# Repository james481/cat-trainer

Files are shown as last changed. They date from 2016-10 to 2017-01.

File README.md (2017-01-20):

# Cat Trainer

## Electronic Feline Warfare for Fun and Profit

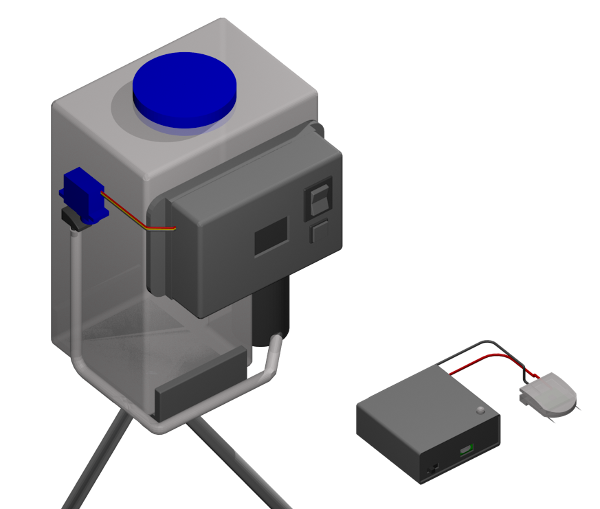
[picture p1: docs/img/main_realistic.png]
Cat Trainer


A microcontroller based system for training cats using accelerometer based sensors to detect clawing of carpet or furniture and automatically discouraging the behavior using sprayed water.

See more details about this project and how it was built [here](https://james481.github.io/cat-trainer/).

__This project has been featured on [Hackaday](http://hackaday.com/2017/01/20/sentry-robot-turns-bad-cat-to-good/). Welcome HaD readers and thanks for checking it out!__

* [Base Software](./base/teensy_base)
* [Base PCB - OSHPark](https://oshpark.com/shared_projects/nA5DhVjQ)
* [Base KiCad Schematic / PCB](./base/teensy_base_pcb)
* [Sensor Software](./sensor/arduino_mma8452)
* [Sensor PCB - OSHPark](https://oshpark.com/shared_projects/1HsJuNbs)
* [Sensor KiCad Schematic / PCB](./sensor/feather32u4_mma8452_pcb)

All code and other materials contained in this repository are copyright (c) 2016 - 2017 James Watts or their respective copyright holders as noted, and is provided under BSD license. For details see [LICENSE.txt](LICENSE.txt).

This device is patent pending. Please [contact me](http://www.jamescwatts.com) for licensing or more information.

[main]: ./docs/img/main_realistic.png

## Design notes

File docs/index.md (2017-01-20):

---
title: Electronic Feline Warfare for Fun and Profit
---

__This project has been featured on [Hackaday](http://www.hackaday.com). Welcome HaD readers and thanks for checking it out!__

## The Problem

My wife and I have a couple of cats in our home, and as any cat owners can tell you they pretty much spend their days either napping or causing problems. One particular problem our cats cause is tearing up the carpets and furniture in our home. This sight is familiar to many cat owners:

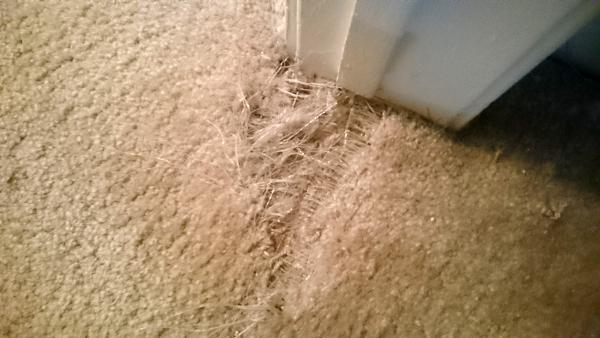
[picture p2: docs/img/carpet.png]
Torn Carpet


We stopped our cats from doing this while we were around by spraying them with a regular hand spray bottle full of water, but as evidenced by the bits of carpet laying everywhere, they still continued doing it when we weren't around to stop them.

---

## The Answer

Cat Trainer

Having recently become interested in programming microcontrollers, I decided to work on an automated solution to my problem. After tinkering with it for a while (close to a year off and on), I ended up building a system based on a central control and spray station gathering data from wireless sensor nodes attached to the carpet near the spots the cats tear up. When the cats pull on the carpet with their claws activating one of the sensors, the base station points a spray nozzle towards the activated sensor and activates a small pump, spraying the cat with water, thus enacting sweet, sweet revenge (and also training them to not scratch in that spot any more).

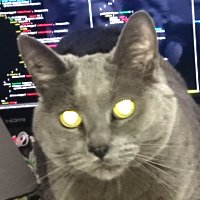
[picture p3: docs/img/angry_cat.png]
Angry Cat


---

## The Design

The first problem to solve was how to detect when my cat was tearing up the carpet with some sort of sensor. Along with detecting the scratching, I wanted the sensor to ignore the cats when they weren't tearing the carpet and just passing by, and also all the other exciting things that happen in the life of a carpet, like being walked on or vacuumed.

### The Sensor Unit

After some testing, I determined that I could detect the motion that the cats clawing causes in the carpet fairly reliably by using an accelerometer set to only report the motion of the carpet being pulled away from the floor underneath by the cat's claws. I ended up choosing the MMA8452Q integrated accelerometer from Freescale Semiconductors, handily available on a fairly inexpensive breakout board from [SparkFun](https://www.sparkfun.com/products/12756). This IC is something similar to what you might find in your cell phone to detect when you turn it on it's side, but reading through the (rather extensive) [data sheet](https://cdn.sparkfun.com/datasheets/Sensors/Accelerometers/MMA8452Q-rev8.1.pdf) yields all sorts of other interesting abilities.

Particular to my needs is the ability to configure the accelerometer IC to internally handle detection of motion events above certain thresholds and in certain axes (so called "transient motion detection"), and to fire interrupts by changing the voltage states of it's external pins when it detects these motion events. This allows the microcontroller to normally run in a very low power state and not constantly monitor the raw sensor data, increasing the sensor node battery life substantially. The sensor IC sitting on it's small breakout board fits snugly in a molded plastic clip designed for hanging papers on cubicle walls, which work perfectly for attaching the sensor temporarily to the carpet.

Accelerometer Sensor

After figuring out what sensor to use, I next needed a microcontroller that could run the sensor a report the data back to the base station using some wireless radio. I considered using an ESP8266 WiFi board, but quickly ran into problems with the power characteristics of that chip, in that it has a low power operating mode, but takes a couple of seconds to resume wireless operation after coming out of sleep, so wouldn't work well for this real time usage. I ended up prototyping the sensor using a basic Arduino Pro Mini / Atmel 328p using a [Nordic NRF24L01+](https://www.amazon.com/gp/product/B00NGCZC0M) 2.4GHz radio chipset for wireless packet communication, along with a RGB LED for status / battery level notification.

Sensor Prototype

The final implemented sensor nodes use a [Feather / Atmel 32u4 board](https://www.adafruit.com/products/2771) from Adafruit and the same Nordic radio chips along with a [1Ah Li-Ion battery](https://www.sparkfun.com/products/13813) for power. The Feather boards are nice because they have the power regulation and charging circuitry for the battery on-board, and also have a voltage divider at the battery input already connected to an analog pin, making monitoring the battery level in software very easy. Finally, they break out the enable pin of the voltage regulator, making adding an on / off switch easy as well. I built the first one by wiring everything together by hand with soldering and short lengths of wire.

Sensor Hand Built

I decided after building the first one that a [PCB](https://oshpark.com/shared_projects/1HsJuNbs) would be much easier than wiring everything by hand, and makes everything look a bit cleaner to boot (although this PCB design has a couple of minor fit issues I'd like to fix).

Sensor PCB

Either way, everything is put into a small [plastic enclosure](https://www.digikey.com/product-detail/en/bud-industries/HP-3650-B/377-1650-ND/2057365) with some silicone wires (JST-XH battery balance extensions) to connect the sensors. Having the sensor units pretty well squared away I moved on to the central control / spray unit, which ended up being somewhat more complex.

---

### The Base Unit

I wanted the base spray unit to handle several tasks:

* Securely contain water used for spraying in a bottle / reservoir
* Pump water through a spray nozzle to create the spray when a sensor is activated
* Allow connection of multiple sensors to cover a larger area
* Position the spray nozzle to point towards the sensor being activated
* Display the battery level and activation counts of the connected sensors
* Allow configuration of the direction for spray for each sensor

This is a lot to ask of one of the smaller Arduino / Atmel boards like the Pro Mini or Feather (although it's probably possible), so I chose a [Teensy 3.2](https://www.pjrc.com/store/teensy32.html) board to power the operation of the base station. This little fella sports a fairly impressive ARM Cortex M4 running at 72 MHz and plenty of flash / RAM / GPIO to play with. Like with the sensor the initial prototype was built on a bread board.

Base Unit Prototype

#### Water Bottle / Pump

The main component of the base station is the water storage and pump to drive the spray nozzle. Lots of different possibilities exist for making something from scratch (especially if a 3d printer is handy), but I decided to just get a pre-built automotive [windshield washer tank](https://www.amazon.com/gp/product/B00495UQT2). This holds much more water than I need, but having the pump built in makes it a convenient part to start with. The pump is designed to run on 12V (as you find in an automobile) but pushes plenty well when given 9V (pulling momentary loads of 1.6A or so). Bonus is that it came with tubing and some spray nozzles (as might be mounted on the hood of your car) and assorted hardware. I used one of the spray nozzles after plugging one side of it with epoxy to spray in a single direction, and some of the hardware to build the mount.

#### Control Spray Nozzle Direction

To position the spray nozzle in different directions to cover multiple sensors, I decided to keep things as simple as possible. I used a [small hobby RC type servo](https://www.amazon.com/gp/product/B0006O3WNW) that I positioned upside down on a simple wire mount epoxied on the side of the tank. This mount also has a horizontal bracket to hold the spray nozzle fitting (that came with the kit). A simple screw straight down through the servo horn into the plastic housing of the spray nozzle completes the connection and allows a fairly wide range (160 degrees or so) of direction adjustment. Modding the servo for continuous rotation or switching to a small stepper motor along with changing the mounting could increase the adjustment range, or for even more mobility the whole thing could be mounted on a mobile chassis.

Spray Nozzle

#### Display Status / Control Sensor Spray Direction

The connected sensor nodes are displayed as icons indicating their current battery level along with the configured direction for them and a count of how many sensor activations have been received on a "postage stamp" [OLED display](https://www.amazon.com/gp/product/B00O2KDQBE). A menu system allows configuration of the base station and connected sensor spray directions via a three position toggle switch and push button (up / down / enter). These are mounted on the outside of a [plastic case](https://www.digikey.com/product-detail/en/bud-industries/CU-18428-B/377-2281-ND/5291583) along with the display, and then the whole thing is epoxied to the water bottle.

Display / Buttons

#### PCB

A custom [PCB](https://oshpark.com/shared_projects/nA5DhVjQ) designed in [KiCad](http://kicad-pcb.org/) provides a home for all the electronics and connections to the pump and servo, and has a barrel connector suitable for a typical 9V / 2A DC converter for power. In addition to the Teensy microcontroller and Nordic radio chip, an H-bridge motor driver IC is used to control the pump (running at 9V), and a pair of voltage regulators provide the 5V and 3.3V supplies to run the servo motor, Teensy, display, and radio.

Base Station PCB

#### Mounting

I decided it would be handy to have some flexibility in the mounting for positioning the unit for maximum effect, and the obvious choice is a standard photography style tripod mount. I used a cheap [universal cell phone tripod mount](https://www.amazon.com/gp/product/B00WFNNNCC), and a few minutes pulling it apart and some liberal dabs of epoxy later the control unit has a solid mount attachment. For covering areas of my carpet a cheap mini tripod to hold the unit a few inches off the floor works just fine.

Base Station Mount

---

## The Results

After all that testing and building, I was really hopeful that I ended up with something useful. In fact, in testing with our cats it works better than I really expected. So well that I've been unable to get a video of one of them being sprayed by it, because within the first night or so of setting it up (about 8 spray activations) they quickly decided to find somewhere else to scratch.

Sweet, sweet success!

Base Station Setup

Base Station Front

---

## Next Steps

Along with some additional features and software tuning still to be done, I did a bit of research to see if I could find anything like this already being made or sold. So far I've yet to come up with anything similar, so I've decided to take steps on patenting this technology while evaluating if it has any commercial potential, and currently this device is patent pending. If you're interested in building one these, please [contact me](http://www.jamescwatts.com). That said, I would love to hear from you if you want to build your own version to use at home, and would be excited to hear about any improvements you may come up with.

---

## Build Your Own

__DISCLAIMER:__ _Although not a particularly dangerous device by electrical standards, this device involves electricity and water (never good when they come together) and possibly other hazards, and suitable judgment must be exercised to determine if the device is built correctly and is safe to operate. No warranty of this device, design or associated software and other materials to be free of defect is provided or implied, and any actual usage of this device is at your own risk! The author disclaims any responsibility for any mishap or zombie apocalypse you may encounter._

All the information you might need to build your own is probably somewhere in this repository, including the software for the base and sensor nodes (as Arduino sketches, able to be loaded to boards via Arduino / Teensyduino IDE), [KiCad](http://kicad-pcb.org/) circuit diagrams and PCB layouts, and even some [FreeCAD](http://www.freecadweb.org/) 3D models of the finished units to explore.

That said, be prepared for some troubleshooting, editing of code, or making adaptations to the design to suit your needs and / or get it all working, this isn't a finished product and will require heavy tinkering!

All of the parts can be sourced from either Amazon or Digikey (among other places), some of which are linked to above. The PCBs that I used to build this can be ordered from OSHPark (or you can modify them from the source files to suit your needs):

* [Base Software]({{ site.github.repository_url }}/blob/master/base/teensy_base/teensy_base.ino)
* [Base PCB - OSHPark](https://oshpark.com/shared_projects/nA5DhVjQ)
* [Base KiCad Schematic / PCB]({{ site.github.repository_url }}/tree/master/base/teensy_base_pcb)
* [Sensor Software]({{ site.github.repository_url }}/blob/master/sensor/arduino_mma8452/arduino_mma8452.ino)
* [Sensor PCB - OSHPark](https://oshpark.com/shared_projects/1HsJuNbs)
* [Sensor KiCad Schematic / PCB]({{ site.github.repository_url }}/tree/master/base/teensy_base_pcb)

Happy hacking!

## Updates

High resolution / additional images are available via [Imgur](http://imgur.com/a/s6DJq).

This project has been featured on [Hackaday](http://hackaday.com/2017/01/20/sentry-robot-turns-bad-cat-to-good/)!

__Licensing:__ It's come to my attention that US patent law (where the patent for this device is pending) may require licensing if you choose to build one of these devices for personal use. My intention in filing for patent protection for this device is due to the (obviously very remote) possibility that it may have widespread commercial appeal and as an exercise in learning to navigate the patent process and system. I fully encourage and support anyone who would like to build or improve this device for personal, non-commercial use and you can [contact me](http://www.jamescwatts.com) if you would like to arrange a license for doing so.

[torn_carpet]: ./img/carpet.png
[main]: ./img/main_realistic.png
[angry_cat]: ./img/angry_cat.png
[sensor_clip]: http://i.imgur.com/HQ5jLZol.png
[sensor_proto]: http://imgur.com/d8skVECl.png
[sensor_hand]: http://imgur.com/Bxe2B9jl.png
[sensor_pcb]: http://imgur.com/T1lvXhsl.png
[base_proto]: http://imgur.com/y3yjc8Al.png
[spray_nozzle]: http://imgur.com/SDXtu9Tl.png
[display_buttons]: http://imgur.com/vd8e7Pvl.png
[base_pcb]: http://imgur.com/OkVIc9Ll.png
[base_mount]: http://imgur.com/wQvpuyJl.png
[base_setup]: http://imgur.com/3iBZtJrl.png
[base_front]: http://imgur.com/htidU3dl.png

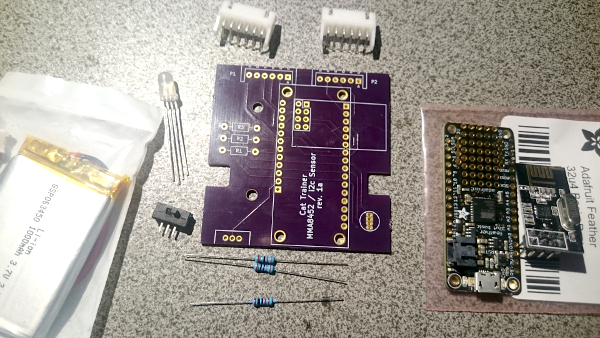
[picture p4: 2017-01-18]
docs/img/sensor_pcb.png

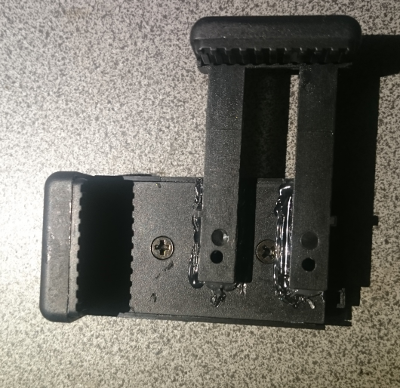
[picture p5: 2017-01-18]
docs/img/base_mount.png

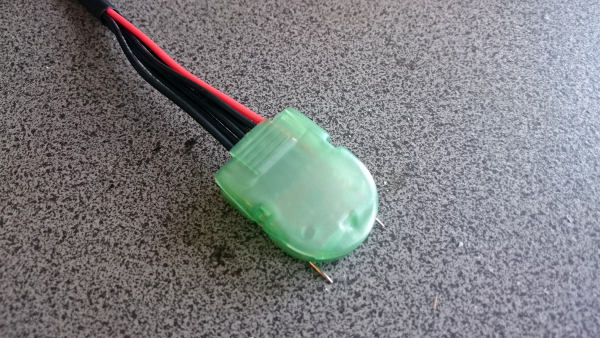
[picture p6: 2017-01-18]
docs/img/sensor_clip.png

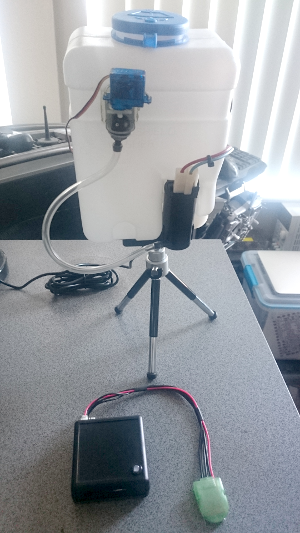
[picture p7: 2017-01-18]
docs/img/base_front.png

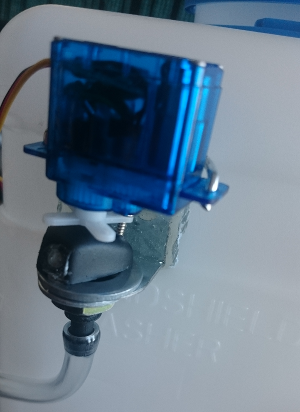
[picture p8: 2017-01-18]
docs/img/spray_nozzle.png

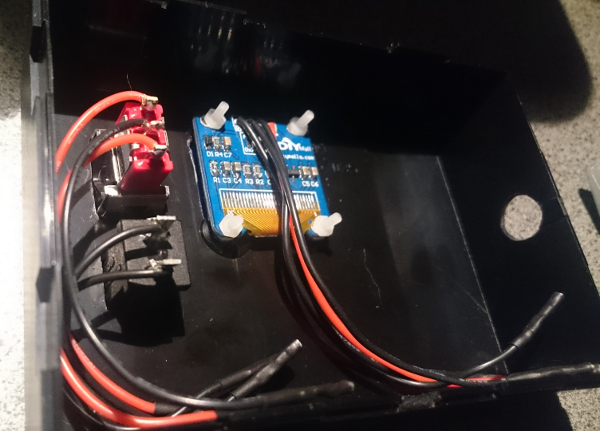
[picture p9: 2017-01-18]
docs/img/display_buttons.png

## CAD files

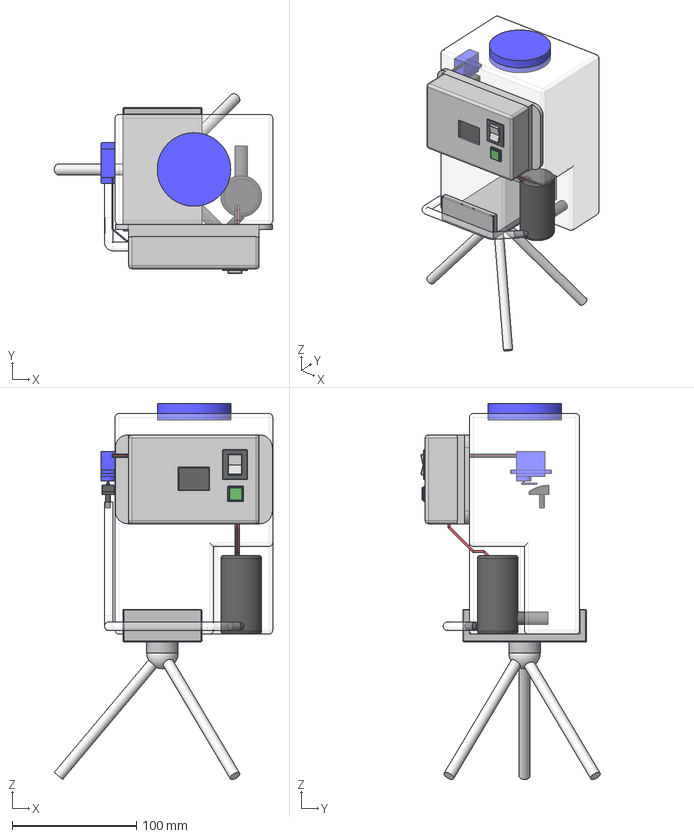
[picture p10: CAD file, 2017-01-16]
base/teensy_base_cad/teensy_base.FCStd
176.1 x 144.8 x 303.0 mm
PumpToTank
PumpOut
PumpMain
Cap
TankMain001
Connect001
CaseBody
SwitchPanel
SwitchBody
ScreenBack
Screen
PCB001
Teensy
NRF
Connector
Cap1
Cap2
Reg1
Reg002
PumpCon
Nozzle
Clamp
Ball
PumpWire1
PumpWire2
Servo1
Servo2
Servo3
Hose

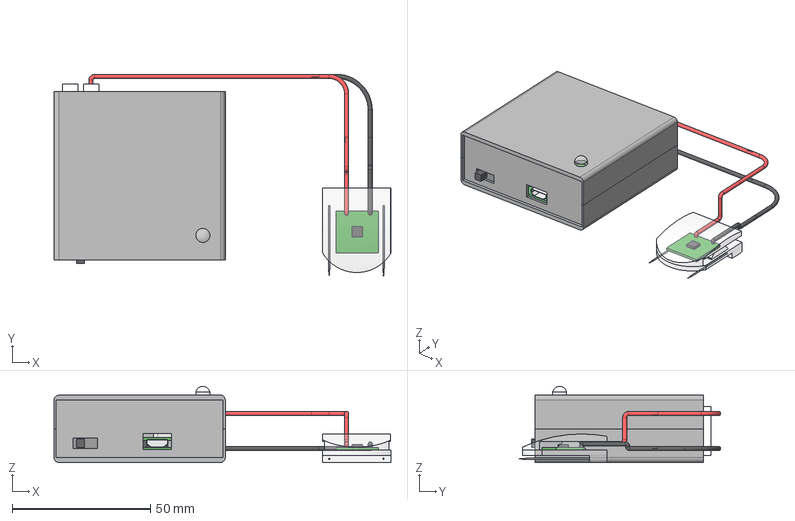
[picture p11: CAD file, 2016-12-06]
sensor/arduino_mma8452_cad/arduino_mma8452.FCStd
122.0 x 72.9 x 27.7 mm
Feather_MCU
Feather_BAT
Feather_PCB
Feather_USB
NRF_PCB
NRF_Headers
NRF_Crystal
NRF_MCU
LED
Panel_Back
Connector1
Connector2
Panel_Front
Panel_Bottom
Panel_Top
MMA_PCB
MMA_MCU
Clip_Top
Pin 1
Pin 2
Clip_Bottom

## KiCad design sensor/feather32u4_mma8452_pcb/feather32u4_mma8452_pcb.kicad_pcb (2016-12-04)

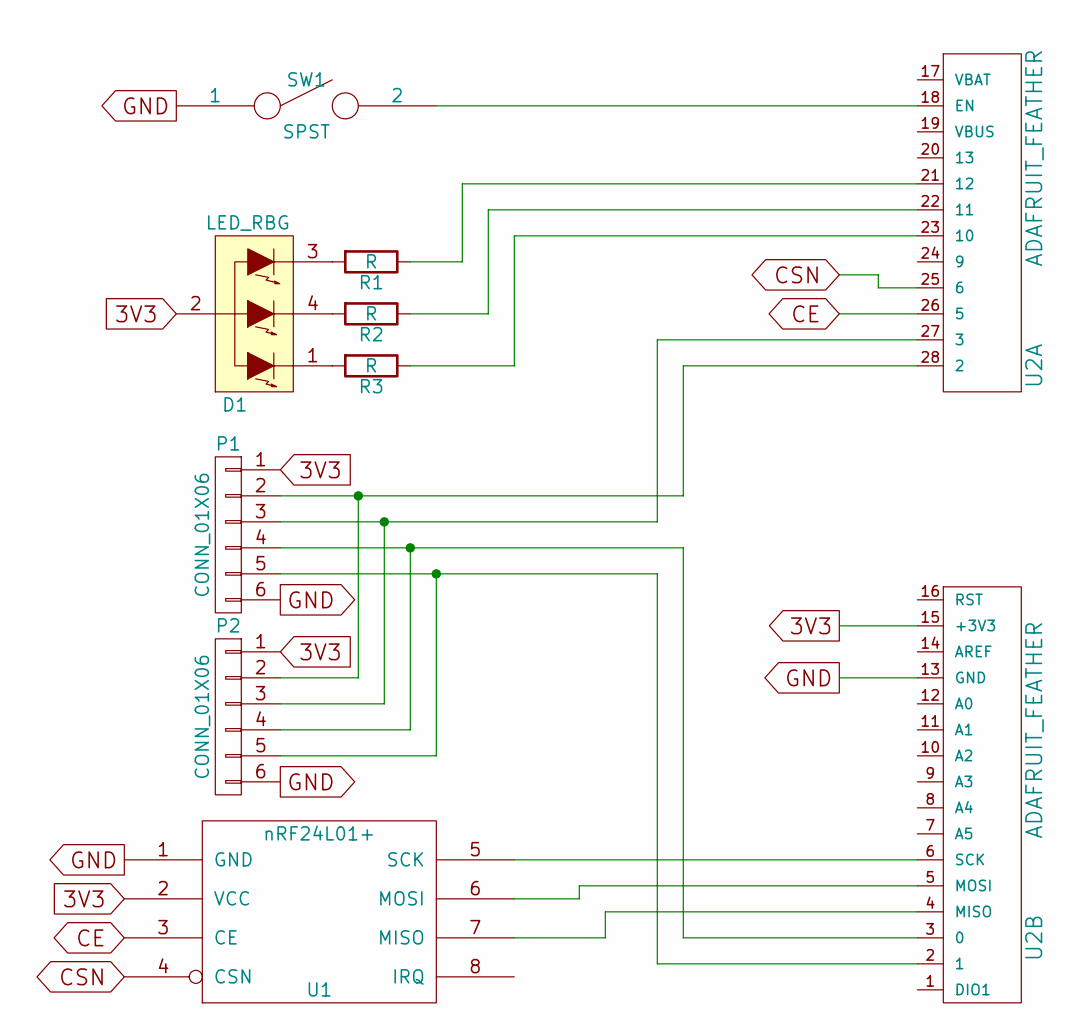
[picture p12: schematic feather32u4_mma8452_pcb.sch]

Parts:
D1: LED_RBG; LED-RGB-5MM_Common_Cathode
P1, P2: CONN_01X06; JST_XH_S06B-XH-A_06x2.50mm_Angled
R1, R2, R3: R; Resistor_Horizontal_RM10mm
SW1: SPST; DPST_TE_SSJ12R04
U1: nRF24L01+; Socket_nRF24L01
U2: ADAFRUIT_FEATHER

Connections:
3V3: D1.2 (COMMON_ANODE), P1.1, P2.1, U1.2 (VCC), U2.15 (+3V3)
CE: U1.3 (CE), U2.26 (5)
CSN: U1.4 (CSN), U2.25 (6)
GND: P1.6, P2.6, SW1.1, U1.1 (GND), U2.13 (GND)
unnamed: D1.1 (RED_CATHODE), R3.2
unnamed: D1.3 (BLUE_CATHODE), R1.2
unnamed: D1.4 (GREEN_CATHODE), R2.2
unnamed: P1.2, P2.2, U2.28 (2)
unnamed: P1.3, P2.3, U2.27 (3)
unnamed: P1.4, P2.4, U2.3 (0)
unnamed: P1.5, P2.5, U2.2 (1)
unnamed: R1.1, U2.21 (12)
unnamed: R2.1, U2.22 (11)
unnamed: R3.1, U2.23 (10)
unnamed: SW1.2, U2.18 (EN)
unnamed: U1.5 (SCK), U2.6 (SCK)
unnamed: U1.6 (MOSI), U2.5 (MOSI)
unnamed: U1.7 (MISO), U2.4 (MISO)

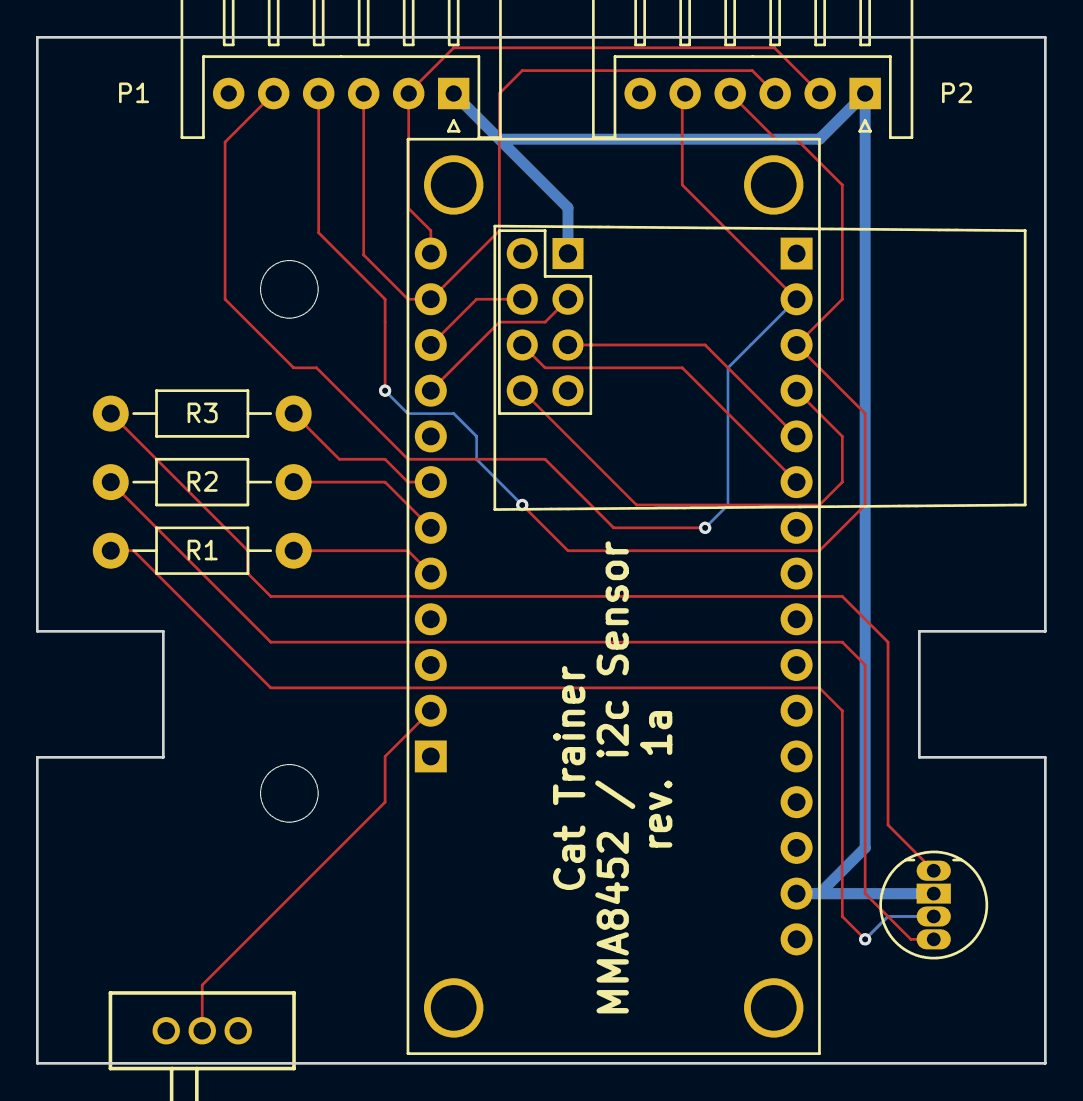
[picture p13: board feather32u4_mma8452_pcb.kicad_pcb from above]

Board: 2 copper layers, 56.0 x 57.0 mm, 9 parts (0 on the bottom side), 18 nets.

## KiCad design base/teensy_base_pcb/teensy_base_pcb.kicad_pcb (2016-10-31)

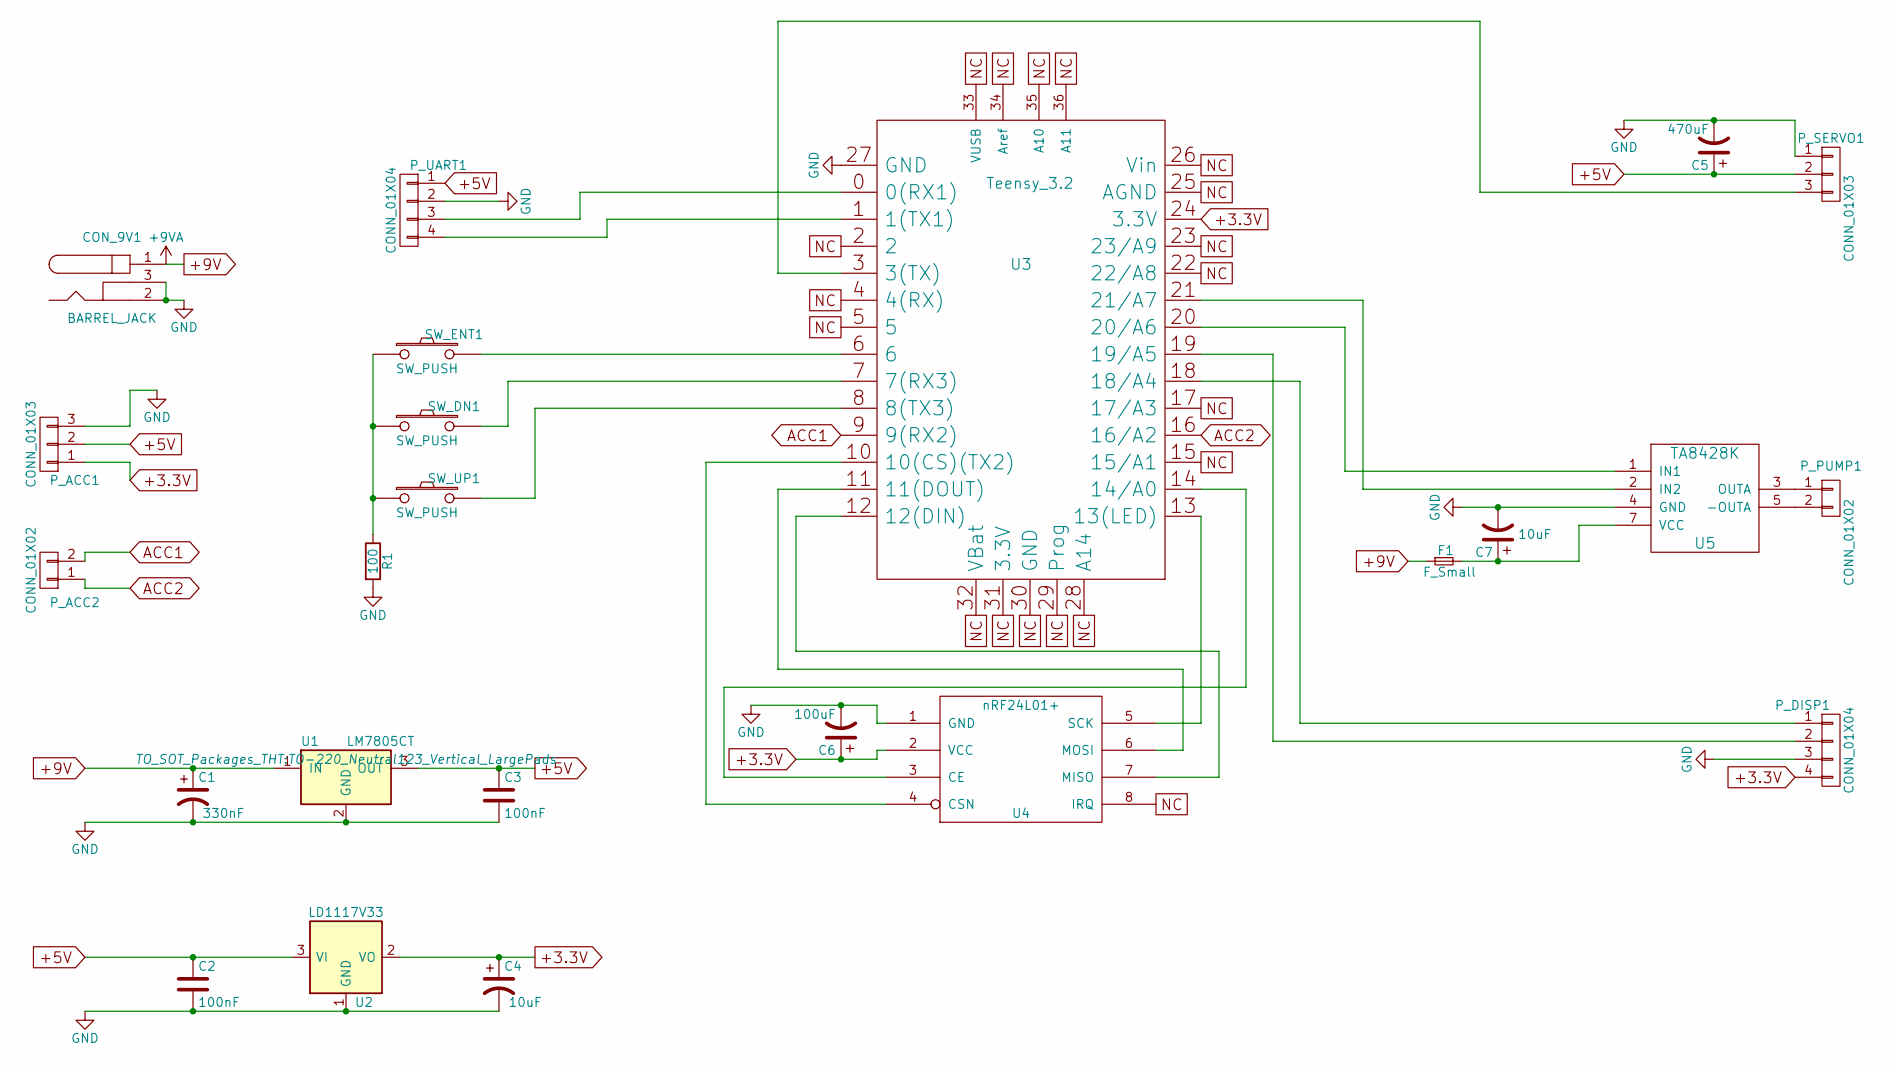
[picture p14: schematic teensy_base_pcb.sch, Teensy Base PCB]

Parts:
C1: 330nF; C_Rect_L7_W2.5_P5
C2, C3: 100nF; C_Rect_L7_W2.5_P5
C4, C7: 10uF; C_Rect_L7_W2.5_P5
C5: 470uF; C_Radial_D8_L13_P3.8
C6: 100uF; C_Radial_D5_L11_P2.5
CON_9V1: BARREL_JACK
F1: F_Small; Fuse_TE5_Littlefuse-395Series
P_ACC1: CONN_01X03; Pin_Header_Straight_1x03
P_ACC2: CONN_01X02; Pin_Header_Straight_1x02
P_DISP1: CONN_01X04; Pin_Header_Angled_1x04
P_PUMP1: CONN_01X02; TerminalBlock_Pheonix_PT-3.5mm_2pol
P_SERVO1: CONN_01X03; Pin_Header_Angled_1x03
P_UART1: CONN_01X04; Socket_Strip_Angled_1x04
R1: 100; Resistor_Horizontal_RM10mm
SW_DN1: SW_PUSH; Pin_Header_Angled_1x02
SW_ENT1: SW_PUSH; Pin_Header_Angled_1x02
SW_UP1: SW_PUSH; Pin_Header_Angled_1x02
U1: LM7805CT; TO-220_Neutral123_Vertical_LargePads
U2: LD1117V33; TO-220_Neutral123_Vertical_LargePads
U3: Teensy_3.2; Teensy-3.1
U4: nRF24L01+; Socket_Strip_Straight_2x04
U5: TA8428K; Socket_Strip_Straight_1x07

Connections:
+3.3V: C4.1, C6.1, P_ACC1.1, P_DISP1.4, U2.2 (VO), U3.24 (3.3V), U4.2 (VCC)
+5V: C2.1, C3.1, C5.1, P_ACC1.2, P_SERVO1.2, P_UART1.1, U1.3 (OUT), U2.3 (VI)
+9V: C1.1, CON_9V1.1, F1.1, U1.1 (IN)
ACC1: P_ACC2.2, U3.9 (9(RX2))
ACC2: P_ACC2.1, U3.16 (16/A2)
GND: C1.2, C2.2, C3.2, C4.2, C5.2, C6.2, C7.2, CON_9V1.2, CON_9V1.3, P_ACC1.3, P_DISP1.3, P_SERVO1.1, P_UART1.2, R1.2, U1.2 (GND), U2.1 (GND), U3.27 (GND), U4.1 (GND), U5.4 (GND)
NC: U3.2, U3.4 (4(RX)), U3.5, U3.15 (15/A1), U3.17 (17/A3), U3.22 (22/A8), U3.23 (23/A9), U3.25 (AGND), U3.26 (Vin), U3.28 (A14), U3.29 (Prog), U3.30 (GND), U3.31 (3.3V), U3.32 (VBat), U3.33 (VUSB), U3.34 (Aref), U3.35 (A10), U3.36 (A11), U4.8 (IRQ)
unnamed: C7.1, F1.2, U5.7 (VCC)
unnamed: P_DISP1.1, U3.18 (18/A4)
unnamed: P_DISP1.2, U3.19 (19/A5)
unnamed: P_PUMP1.1, U5.3 (OUTA)
unnamed: P_PUMP1.2, U5.5 (-OUTA)
unnamed: P_SERVO1.3, U3.3 (3(TX))
unnamed: P_UART1.3, U3.0 (0(RX1))
unnamed: P_UART1.4, U3.1 (1(TX1))
unnamed: R1.1, SW_DN1.1, SW_ENT1.1, SW_UP1.1
unnamed: SW_DN1.2, U3.7 (7(RX3))
unnamed: SW_ENT1.2, U3.6
unnamed: SW_UP1.2, U3.8 (8(TX3))
unnamed: U3.10 (10(CS)(TX2)), U4.4 (CSN)
unnamed: U3.11 (11(DOUT)), U4.6 (MOSI)
unnamed: U3.12 (12(DIN)), U4.7 (MISO)
unnamed: U3.13 (13(LED)), U4.5 (SCK)
unnamed: U3.14 (14/A0), U4.3 (CE)
unnamed: U3.20 (20/A6), U5.1 (IN1)
unnamed: U3.21 (21/A7), U5.2 (IN2)

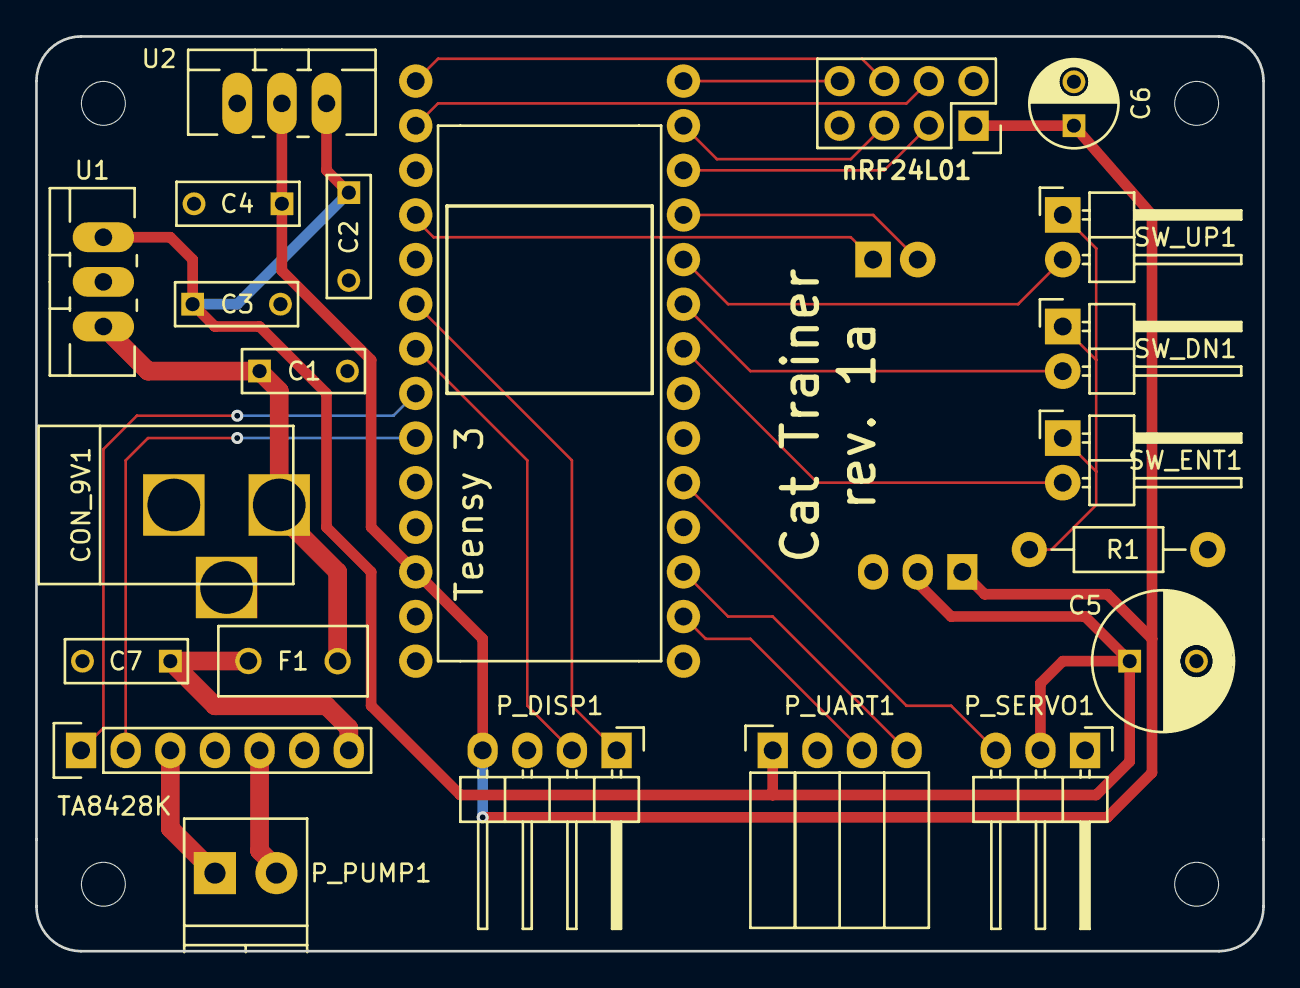
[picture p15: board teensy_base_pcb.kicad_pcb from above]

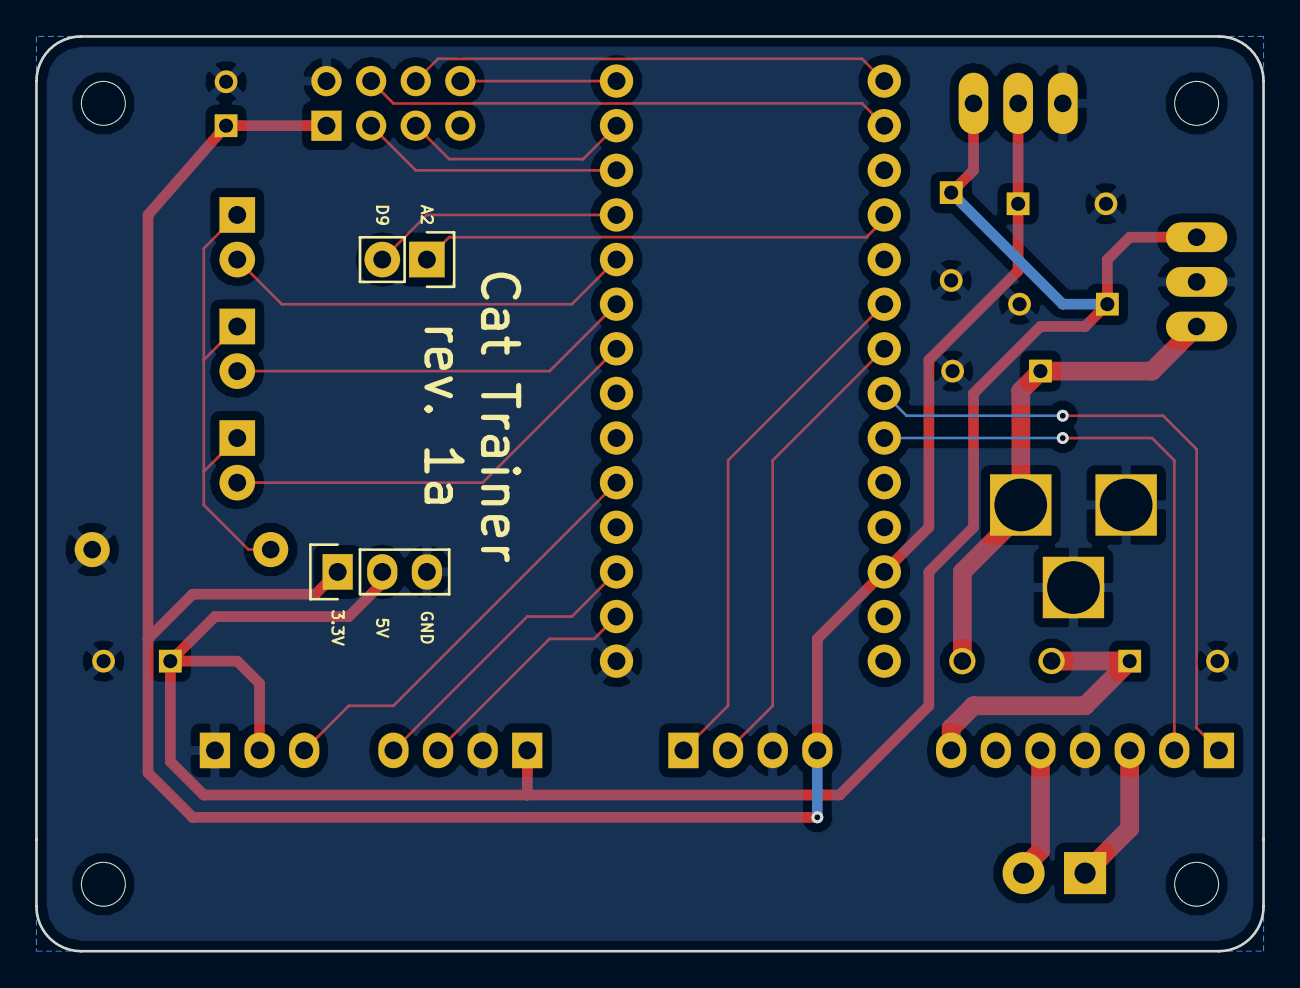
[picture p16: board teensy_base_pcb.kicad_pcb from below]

Board: 2 copper layers, 69.9 x 52.1 mm, 24 parts (2 on the bottom side), 26 nets.

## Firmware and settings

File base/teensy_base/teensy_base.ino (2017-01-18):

/*
 * teensy_base.ino
 *
 * Behavior correction base station utilizing DC pump sprayhead and
 * communicating via NRF24L01+ to remote sensor nodes on an Teensy 3.x
 * compatible host.
 *
 * Copyright (c) 2016 - 2017, James Watts
 * All rights reserved, no unauthorized distribution or reproduction.
 *
 * See LICENSE.txt for details.
 */

#include <functional>
#include <SPI.h>
#include <Wire.h>
#include <EEPROM.h>
#include <Adafruit_GFX.h>
#include <Adafruit_SSD1306.h>
#include "nRF24L01.h"
#include "RF24.h"
#include "printf.h"
#include <Servo.h>
#include <Bounce.h>
#include "ct_sensor.h"

/*
 * Configuration
 */

#define MENU_TIMEOUT 10000 // ms until menu exits
#define SENSOR_MAX 4 // No more than 4 on NRF24L01
#define DISPLAY_INVERT 30 // Seconds between status display invert
#define DISPLAY_DIM 30 // Seconds until display dim
#define DEBUG true
#define DEBUGOUT Serial

// NRF24L01
#define GPIO_RF24_CE 14
#define GPIO_RF24_CSN 10

// Buttons
#define GPIO_BTN_ENTER 6
#define GPIO_BTN_DN 7
#define GPIO_BTN_UP 8
#define GPIO_DEBOUNCE 10
#define GPIO_BTN_HOLD_DELAY 500

// Pump / Servo
#define SERVO_MOVE_DELAY 500
#define PUMP_SPRAY_LENGTH 1000
#define GPIO_SPRAY_PUMP A6
#define GPIO_SPRAY_PUMP2 A7
#define GPIO_SPRAY_SERVO 3
#define SERVO_MIN_LEN 1050
#define SERVO_MAX_LEN 2050

#define GPIO_OLED_RESET 17

/*
 * Hardware Config
 */

// NRF24L01+ Setup
RF24 radio(GPIO_RF24_CE, GPIO_RF24_CSN);

// Display Setup
Adafruit_SSD1306 display(GPIO_OLED_RESET);

// Servo Setup
Servo sprayServo;

// Buttons
Bounce buttonEnter(GPIO_BTN_ENTER, GPIO_DEBOUNCE);
Bounce buttonDown(GPIO_BTN_DN, GPIO_DEBOUNCE);
Bounce buttonUp(GPIO_BTN_UP, GPIO_DEBOUNCE);

// Button States: 0 - None, 1 - Click, 2 - Hold
struct ButtonState {
  uint8_t enter = 0;
  uint8_t up = 0;
  uint8_t down = 0;
  bool pushed = false;
} btnState;

/*
 * Sensor ID / Packet Storage
 */
Sensor sensors[SENSOR_MAX];
SensorUid remoteUid;
DataPacket recvPacket, sendPacket;

const uint8_t sensorBaseIds[4] = { 0xB1, 0xC2, 0xD3, 0xE4 };

/*
 * Master / Spray / Movement / Menu States and Timers
 */
bool masterActive = true;
bool menuActive = false;
bool redrawStatus = false;
int8_t sprayActive = -1;
int8_t sprayNeeded = -1;

uint8_t sprayPos = 90;
uint8_t sprayMoving = 0;

bool displayInvert = false;
uint8_t displayInvertTimer = 0;

bool displayDim = false;
uint8_t displayDimTimer = 0;

elapsedMillis sprayTimer;
elapsedMillis statusTimer;
elapsedMillis menuTimer;

/*
 * Menu Classes
 */
class MenuItem;
class MenuDisplay;

class MenuItem {
  public:
    MenuItem(const char* label, const uint8_t uid) : itemLabel(label), itemUid(uid) {
      parent = child = above = below = 0;
    }

    const bool isActive() {
      if (activeCb) {
        return(activeCb(*this));
      }
      return(true);
    }

    const char* getLabel(bool useCb = true) {
      if (labelCb && useCb) {
        return(labelCb(*this));
      }
      return(itemLabel);
    }

    char* getValue() {
      if (valueCb) {
        valueCb(*this, itemVal);
      }

      return(itemVal);
    }

    const uint8_t getUid() const {
      return(itemUid);
    }

    MenuItem *getAbove(bool onlyActive = false) const {
      if (onlyActive && above) {
        return((above->isActive()) ? above : above->getAbove(true));
      }
      return(above);
    }

    MenuItem *getBelow(bool onlyActive = false) {
      if (onlyActive && below) {
        return((below->isActive()) ? below : below->getBelow(true));
      }
      return(below);
    }

    MenuItem *getChild(bool onlyActive = true, bool useCb = true) {
      if (childCb && useCb) {
        return(childCb(*this));
      }

      if (onlyActive && child && !child->isActive() && child->getBelow()) {
        return(child->getBelow(true));
      }

      return(child);
    }

    MenuItem *getParent() const {
      return(parent);
    }

    bool getItemEditable() {
      return(itemEditable);
    }

    void handleEdit(ButtonState btns) {
      if (editCb) {
        editCb(*this, btns);
      }
    }

    MenuItem &setParent(MenuItem &item) {
      parent = &item;
      return(*this);
    }

    MenuItem &setChild(MenuItem &item) {
      child = &item;
      item.parent = this;

      return(*this);
    }

    MenuItem &setItemEditable(bool editable) {
      itemEditable = editable;
      return(*this);
    }

    MenuItem &addAbove(MenuItem &item) {
      item.below = this;
      above = &item;
      return(*this);
    }

    MenuItem &addBelow(MenuItem &item) {
      item.above = this;
      below = &item;
      return(*this);
    }

    bool hasValue() {
      return((valueCb) ? true : false);
    }

    bool isEqual(MenuItem &item) {
      return(getUid() == item.getUid());
    }

    bool isEqual(MenuItem *item) {
      return(getUid() == item->getUid());
    }

    MenuItem &setActiveCb(std::function<bool (MenuItem &item)> acb) {
      activeCb = acb;
      return(*this);
    }

    MenuItem &setChildCb(std::function<MenuItem* (MenuItem &item)> cb) {
      childCb = cb;
      return(*this);
    }

    MenuItem &setEditCb(std::function<void (MenuItem &item, ButtonState &btns)> cb) {
      editCb = cb;
      return(*this);
    }

    MenuItem &setLabelCb(std::function<const char* (MenuItem &item)> cb) {
      labelCb = cb;
      return(*this);
    }

    MenuItem &setValueCb(std::function<void (MenuItem &item, char* val)> cb) {
      valueCb = cb;
      return(*this);
    }

  protected:
    const char* itemLabel;
    char itemVal[10];
    const uint8_t itemUid;
    bool itemEditable = false;

    // Linked Matrix
    MenuItem *above;
    MenuItem *below;
    MenuItem *child;
    MenuItem *parent;

    // Event Callback Lambdas
    std::function<bool (MenuItem &item)> activeCb;
    std::function<MenuItem* (MenuItem &item)> childCb;
    std::function<void (MenuItem &item, ButtonState &btns)> editCb;
    std::function<const char* (MenuItem &item)> labelCb;
    std::function<void (MenuItem &item, char* val)> valueCb;
};

class MenuDisplay {
  public:
    MenuDisplay(Adafruit_SSD1306 *dis, MenuItem *rootItem) : oled(dis), root(rootItem) {
      current = root;
      first = root;
    }

    MenuItem getRoot() {
      return(*root);
    }

    MenuItem getCurrent() {
      return(*current);
    }

    MenuItem getFirst() {
      return(*first);
    }

    bool handleButtons(ButtonState btns) {
      bool redraw = false;

#if DEBUG
      printf_P(
        PSTR("handleButtons: Current %s (%d).\r\n"),
        current->getLabel(),
        current->getUid()
      );
#endif

      // Handle Enter press / hold
      if (btns.enter == 1) {
        if (isEditing) {
          isEditing = false;
          redraw = true;
        } else if (current->getItemEditable()) {
          isEditing = true;
          redraw = true;
        } else if (current->getChild()) {
          setCurrent(current->getChild());
          findFirst(current);
          redraw = true;
        }
      } else if (btns.enter == 2) {
        if (isEditing) {
          isEditing = false;
          redraw = true;
        } else if (current->getParent()) {
          setCurrent(current->getParent());
          findFirst(current);
          redraw = !current->isEqual(root);
        }

        if (current->isEqual(root)) {
          redraw = false;
        }
      }

      // Handle Up / Down press
      if (isEditing && (btns.up || btns.down)) {
        current->handleEdit(btns);
        redraw = true;
      } else if (btns.up && current->getAbove(true)) {
        setCurrent(current->getAbove(true));
        redraw = true;
      } else if (btns.down && current->getBelow(true)) {
        setCurrent(current->getBelow(true));
        redraw = true;
      }

      if (redraw) {
        redrawMenu();
      }

      return(!current->isEqual(root));
    }

    void resetMenu(void) {
      isEditing = false;
      setCurrent(root);
    }

  private:
    void findFirst(MenuItem *newcur) {
      if (newcur) {
        if (newcur->getAbove()) {
          findFirst(newcur->getAbove());
        } else {
          first = newcur;
        }
      }
    }

    void redrawMenu() {
#if DEBUG
      DEBUGOUT.println(F("Redrawing Menu Display."));
#endif

      Adafruit_SSD1306 display = *oled;
      display.clearDisplay();
      display.dim(false);
      display.setTextSize(1);
      display.setCursor(0, 0);
      display.invertDisplay(0);

      MenuItem *cur = first;

      if (cur->getParent()) {
        display.println(cur->getParent()->getLabel());
        display.println();
      }

      while (cur) {
        if (cur == current) {
          display.setTextColor(BLACK, WHITE);
        } else {
          display.setTextColor(WHITE);
        }

        if (cur->isActive()) {
          if (cur->hasValue()) {

            int padding =
              21 - strlen(cur->getLabel()) - strlen(cur->getValue());
            padding = (padding > 0) ? padding : 0;

            if (isEditing) { display.setTextColor(WHITE); }

            display.print(cur->getLabel());

            while (padding > 0) {
              display.print(" ");
              padding--;
            }

            if ((cur == current) && isEditing) {
              display.setTextColor(BLACK, WHITE);
            }

            display.println(cur->getValue());
          } else {
            display.println(cur->getLabel());
          }
        }

        cur = cur->getBelow();
      }

      display.display();
    }

    void setCurrent(MenuItem *newcur) {
      if (newcur) {
        current = newcur;
      }
    }

    Adafruit_SSD1306 *oled;
    MenuItem *root;
    MenuItem *current;
    MenuItem *first;
    bool isEditing = false;
};

// Menu item objects, note UIDs are used for functional purposes.
MenuItem mi_root("Main Menu", 1);

MenuItem mi_sensors("Sensors", 9);
MenuItem mi_sensor1("Sensor 1", 10);
MenuItem mi_sensor2("Sensor 2", 11);
MenuItem mi_sensor3("Sensor 3", 12);
MenuItem mi_sensor4("Sensor 4", 13);
MenuItem mi_sensorN("No Sensors Found", 15);

MenuItem mi_sensor_active("Active:", 20);
MenuItem mi_sensor_dir("Direction:", 21);
MenuItem mi_sensor_vbat("Battery:", 22);
MenuItem mi_sensor_lastseen("Last Seen:", 23);

MenuItem mi_master("Master Active:", 100);

MenuDisplay menu(&display, &mi_root);

/*
 * This ugly bit of hackery is needed for functional
 * to compile using some types of lambdas.
 */
namespace std
{
  void __throw_bad_function_call()
  {
  }
}


void setup(void);
void loop(void);
void setupRadio(void);
void setupDisplay(void);
void setupMenu(void);
void checkButtons(void);
void checkMenuDisplay(void);
void checkSprayServoTimeout(void);
void checkStartSpray(void);
void handleRadioPacket(void);
void handleSensorData(uint8_t sindex, DataPacket &status);
void handleSensorStatus(uint8_t sindex, DataPacket &status);
bool handleSyncRequest(DataPacket &req);
bool acknowledgeSensor(Sensor &sen);
bool desyncronizeSensor(SensorUid &sid);
void redrawStatusDisplay(void);

/*
 * Setup / Initialize
 */
void setup(void) {

#if DEBUG
  DEBUGOUT.begin(9600);
  printf_begin();
  DEBUGOUT.println(F(""));
  delay(1000);
#endif

  // Setup Buttons
  pinMode(GPIO_BTN_ENTER, INPUT_PULLUP);
  pinMode(GPIO_BTN_DN, INPUT_PULLUP);
  pinMode(GPIO_BTN_UP, INPUT_PULLUP);

  // Setup Spray Pump
  pinMode(GPIO_SPRAY_PUMP, OUTPUT);
  analogWrite(GPIO_SPRAY_PUMP, 0);
  pinMode(GPIO_SPRAY_PUMP2, OUTPUT);
  analogWrite(GPIO_SPRAY_PUMP2, 0);

  // Setup Servo
  sprayServo.attach(GPIO_SPRAY_SERVO, SERVO_MIN_LEN, SERVO_MAX_LEN);
  sprayServo.write(90);
  sprayPos = 90;

  setupRadio();
  setupMenu();

#if DEBUG
  DEBUGOUT.println(F("Base Ready."));
#endif

  // Setup Display / Show Splash
  setupDisplay();
}

/*
 * Main Loop
 */
void loop(void) {

  // Check Spray / Servo Moving Timeouts.
  checkSprayServoTimeout();

  // Check Input Button Status
  checkButtons();

  // Check Menu / Timeout Status
  checkMenuDisplay();

  // Check Spray Start / Stop Status
  checkStartSpray();

  // Check Radio For Packets
  handleRadioPacket();

  // TODO Update EEPROM Sensor Storage

  // Update Status / Display
  if (statusTimer > 1000) {

    // Check Registered Sensors / Update Status
    for (int i = 0; i < SENSOR_MAX; i++) {
      if (sensors[i].lastSeen < 255) {
        sensors[i].lastSeen++;
      }
    }

    // TODO Check Water Level Status

    // Update Status Display
    redrawStatus = true;
    if (displayInvertTimer > DISPLAY_INVERT) {
      displayInvert = !displayInvert;
      displayInvertTimer = 0;
    }
    displayInvertTimer++;

    if (displayDimTimer > DISPLAY_DIM) {
      displayDim = true;
    } else {
      displayDim = false;
      displayDimTimer++;
    }

    statusTimer = 0;
  }

  if (!menuActive && redrawStatus) {
    redrawStatusDisplay();
  }
}

/*
 * Check Button States
 */
void checkButtons(void) {

  btnState.enter = 0;
  btnState.up = 0;
  btnState.down = 0;
  btnState.pushed = false;

  // Check if enter button pressed
  buttonEnter.update();
  if (buttonEnter.fallingEdge()) {
    menuTimer = 0;
  } else if (buttonEnter.risingEdge()) {
    btnState.pushed = true;
    btnState.enter = (menuTimer > GPIO_BTN_HOLD_DELAY) ? 2 : 1;
  }

  // Check if direction buttons pressed (if menu is active)
  if (!btnState.pushed && menuActive) {
    buttonUp.update();
    if (buttonUp.fallingEdge()) {
      menuTimer = 0;
    } else if (buttonUp.risingEdge()) {
      btnState.pushed = true;
      btnState.up = (menuTimer > GPIO_BTN_HOLD_DELAY) ? 2 : 1;
    }
  }

  if (!btnState.pushed && menuActive) {
    buttonDown.update();
    if (buttonDown.fallingEdge()) {
      menuTimer = 0;
    } else if (buttonDown.risingEdge()) {
      btnState.pushed = true;
      btnState.down = (menuTimer > GPIO_BTN_HOLD_DELAY) ? 2 : 1;
    }
  }

#if DEBUG
  if (btnState.pushed) {
    printf_P(
      PSTR("checkButtons: Button state read E: %d U: %d D: %d\r\n"),
      btnState.enter,
      btnState.up,
      btnState.down
    );
  }
#endif

}

/*
 * Check if displayed menu has update / timeout.
 */
void checkMenuDisplay(void) {
  // Timeout Menu display
  if (menuActive && (menuTimer > MENU_TIMEOUT)) {
    menuActive = false;
    menuTimer = 0;
    menu.resetMenu();
    return;
  }

  // Show Menu if not active
  if ((!menuActive) && (btnState.enter > 0)) {
    menuActive = true;
    menuTimer = 0;
  }

  if (menuActive && btnState.pushed) {
    displayDim = false;
    displayDimTimer = 0;
    menuActive = menu.handleButtons(btnState);

#if DEBUG
    MenuItem cur = menu.getCurrent();
    printf_P(
      PSTR("checkMenuDisplay: Menu %s active, current now %s (%d).\r\n"),
      (menuActive) ? "is" : "is not",
      cur.getLabel(),
      cur.getUid()
    );
#endif

  }
}

/*
 * Check Timeouts of Spray / Servo Moving.
 */
void checkSprayServoTimeout(void) {
  // Check Spray timeout status
  if ((sprayActive != -1) && (sprayTimer > PUMP_SPRAY_LENGTH)) {
    analogWrite(GPIO_SPRAY_PUMP2, 0);
    sprayActive = -1;
    sprayTimer = 0;
  }

  // Check Servo Moving Status
  if ((sprayMoving > 0) && (sprayTimer > SERVO_MOVE_DELAY)) {
    sprayPos = sprayMoving;
    sprayMoving = 0;
    sprayTimer = 0;
  }
}

/*
 * Check Spray Needed Status And Start Spray / Servo Move.
 */
void checkStartSpray(void) {
  // Check Spray Start / Stop Status
  if (
    masterActive &&
    !menuActive &&
    (sprayNeeded != -1) &&
    (sprayMoving == 0) &&
    (sprayActive == -1)
  ) {

    Sensor sens = sensors[sprayNeeded];
    if (!sens.baseId || !sens.active) {

#if DEBUG
      printf_P(
        PSTR("checkStartSpray: Sensor not active or no baseId for %d.\r\n"),
        sprayNeeded
      );
#endif

      sprayNeeded = -1;
      return;
    }

    // Check servo position
    if (sens.direction == sprayPos) {
      // Activate Spray
      sprayActive = sprayNeeded;
      sprayNeeded = -1;
      analogWrite(GPIO_SPRAY_PUMP2, 255);

#if DEBUG
      printf_P(
        PSTR("checkStartSpray: Activating spray towards sensor %s (%d).\r\n"),
        sens.id.stype,
        sens.id.uid
      );
#endif

    } else {
      // Move servo to spray position.
      sprayMoving = sens.direction;
      sprayServo.write(sens.direction);

#if DEBUG
      printf_P(
        PSTR("checkStartSpray: Moving servo towards sensor %s (%d): %d.\r\n"),
        sens.id.stype,
        sens.id.uid,
        sens.direction
      );
#endif

    }

    sprayTimer = 0;
  }
}

/*
 * Acknowledge Sensor Or Status Data With OK
 */
bool acknowledgeSensor(Sensor &sen) {
  bool sent = false;
  radio.stopListening();

  sendPacket.id.copyFrom(sen.id);
  sendPacket.ptype = PTYPE_OK;

  radio.openWritingPipe(sensor_send_pipe_mask | sen.baseId);
  sent = radio.write(&sendPacket, sizeof(DataPacket));

#if DEBUG
  if (sent) {
    printf_P(
      PSTR("acknowledgeSensor: Sent Acknowledge to %s (%d) on pipe %02X.\r\n"),
      sen.id.stype,
      sen.id.uid,
      sen.baseId
    );
  } else {
    printf_P(
      PSTR("acknowledgeSensor: Failed to send Acknowledge to %s (%d) on pipe %02X.\r\n"),
      sen.id.stype,
      sen.id.uid,
      sen.baseId
    );
  }
#endif

  radio.startListening();
  return(sent);
}

/*
 * Send A Desyncronize Packet To A Sensor By ID
 */
bool desyncronizeSensor(SensorUid &sid) {
  bool sent = false;
  radio.stopListening();

  sendPacket.id.copyFrom(sid);
  sendPacket.ptype = PTYPE_DESYNC;

  radio.openWritingPipe(control_pipes[0]);
  sent = radio.write(&sendPacket, sizeof(DataPacket));

#if DEBUG
  if (sent) {
    printf_P(
      PSTR("desyncronizeSensor: Sent Desyncronize request to %s (%d).\r\n"),
      sid.stype,
      sid.uid
    );
  } else {
    printf_P(
      PSTR("desyncronizeSensor: Failed to send Desyncronize request to %s (%d).\r\n"),
      sid.stype,
      sid.uid
    );
  }
#endif

  radio.startListening();
  return(sent);
}

/*
 * Handle Sensor Trigger Data Packet
 */
void handleSensorData(uint8_t sindex, DataPacket &status) {
  if (sensors[sindex].baseId) {
    sensors[sindex].lastSeen = 0;
    sensors[sindex].vbat = status.batlevel;

    // TODO Debounce / Queue Triggers
    if (sensors[sindex].active && (sprayNeeded == -1)) {
      if (sensors[sindex].activated < 999) {
        sensors[sindex].activated++;
      }

      sprayNeeded = sindex;
    }

#if DEBUG
    printf_P(
      PSTR("handleSensorData: Handle sensor trigger %s (%d): %d.\r\n"),
      sensors[sindex].id.stype,
      sensors[sindex].id.uid,
      sensors[sindex].vbat
    );
#endif
  }
}

/*
 * Handle Sensor Status Update Packet
 */
void handleSensorStatus(uint8_t sindex, DataPacket &status) {
  // Reset sensor last seen / battery voltage
  if (sensors[sindex].baseId) {
    sensors[sindex].lastSeen = 0;
    sensors[sindex].vbat = status.batlevel;

#if DEBUG
    printf_P(
      PSTR("handleSensorStatus: Updated sensor status %s (%d): %d.\r\n"),
      sensors[sindex].id.stype,
      sensors[sindex].id.uid,
      sensors[sindex].vbat
    );
#endif
  }
}

/*
 * Handle Request To Syncronize Sensor
 */
bool handleSyncRequest(DataPacket &req) {
  bool sent = false;
  int sindex = -1;
  int freeindex = -1;
  uint8_t newId = 0;

  // Find existing or free sensor in storage
  for (int i = 0; i < SENSOR_MAX; i++) {
    if (sensors[i].isEqual(req.id)) {
      sindex = i;
      break;
    }

    if (!sensors[i].baseId && (freeindex == -1)) {
      freeindex = i;
    }
  }

  if (sindex != -1) {
    sensors[sindex].lastSeen = 0;
    sensors[sindex].vbat = req.batlevel;
    newId = sensors[sindex].baseId;

#if DEBUG
    printf_P(
      PSTR("handleSyncRequest: Found existing record %d for %s (%d): %02X.\r\n"),
      sindex,
      sensors[sindex].id.stype,
      sensors[sindex].id.uid,
      newId
    );
#endif

  } else if (freeindex != -1) {
    // Create sensor storage
    sensors[freeindex].id.copyFrom(req.id);
    sensors[freeindex].lastSeen = 0;
    sensors[freeindex].vbat = req.batlevel;
    newId = sensorBaseIds[freeindex];
    sensors[freeindex].baseId = newId;
    sensors[freeindex].active = true;

#if DEBUG
    printf_P(
      PSTR("handleSyncRequest: Stored new record %d for %s (%d): %02X.\r\n"),
      freeindex,
      sensors[freeindex].id.stype,
      sensors[freeindex].id.uid,
      newId
    );
#endif

  } else {
    newId = 0;

#if DEBUG
    printf_P(
      PSTR("handleSyncRequest: Unable to store record for %s (%d).\r\n"),
      req.id.stype,
      req.id.uid
    );
#endif

  }

  // Return response with pipe id.
  radio.stopListening();

  sendPacket.id.copyFrom(req.id);
  sendPacket.ptype = PTYPE_SYNCRES;
  sendPacket.spipe = newId;
  sendPacket.batlevel = req.batlevel;

  radio.openWritingPipe(control_pipes[0]);
  sent = radio.write(&sendPacket, sizeof(DataPacket));

#if DEBUG
  if (sent) {
    printf_P(
      PSTR("handleSyncRequest: Sent Syncronize response to %s (%d): %02X.\r\n"),
      sendPacket.id.stype,
      sendPacket.id.uid,
      sendPacket.spipe
    );
  } else {
    printf_P(
      PSTR("handleSyncRequest: Failed to send Syncronize response to %s (%d).\r\n"),
      sendPacket.id.stype,
      sendPacket.id.uid
    );
  }
#endif

  radio.startListening();
  return(sent);
}
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

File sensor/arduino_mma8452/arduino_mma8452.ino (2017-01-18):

/*
 * arduino_mma8452.ino
 *
 * Remote behavior detection node using MMA8452 accelerometer and NRF24L01+ on
 * an Arduino compatible host.
 *
 * Copyright (c) 2016 - 2017, James Watts
 * All rights reserved, no unauthorized distribution or reproduction.
 *
 * See LICENSE.txt for details.
 */

#include <avr/sleep.h>
#include <avr/power.h>
#include <avr/wdt.h>
#include <SPI.h>
#include <Wire.h>
#include <EEPROM.h>
#include "nRF24L01.h"
#include "RF24.h"
#include "printf.h"
#include "ct_sensor.h"

/*
 * Configuration
 */
#define DEBUG false
#define FEATHER32U4 true
#define BAT_VCC_HIGH 40
#define BAT_VCC_MED 35

// Status LED interval - Watchdog 8 sec cycle count
#define STATUS_FLASH_DELAY 4

/*
 * GPIO Connections
 */
#ifndef FEATHER32U4

// Arduino Pro Mini, etc:
#define GPIO_RF24_CE 7
#define GPIO_RF24_CSN 8
#define GPIO_MMA_IRQ1 2
#define GPIO_MMA_IRQ2 3
#define GPIO_LED_R 5
#define GPIO_LED_G 6
#define GPIO_LED_B 9

#else

// Feather 32u4 (Production):
#define GPIO_RF24_CE 5
#define GPIO_RF24_CSN 6
#define GPIO_MMA_IRQ1 2
#define GPIO_MMA_IRQ2 3
#define GPIO_LED_R 10
#define GPIO_LED_G 11
#define GPIO_LED_B 12
#define FEATHER32U4_BATTERY_PIN A9

#endif

/*
 * MMA8452 Registers
 */
#define ADDR 0x1D
#define STATUS 0x00
#define OUT_X_MSB 0x01
#define OUT_X_LSB 0x02
#define OUT_Y_MSB 0x03
#define OUT_Y_LSB 0x04
#define OUT_Z_MSB 0x05
#define OUT_Z_LSB 0x06
#define SYSMOD 0x0B
#define INT_SOURCE 0x0C
#define WHO_AM_I 0x0D
#define XYZ_DATA_CFG 0x0E
#define HP_FILTER_CUTOFF 0x0F
#define TRANSIENT_CFG 0x1D
#define TRANSIENT_SRC 0x1E
#define TRANSIENT_THS 0x1F
#define TRANSIENT_COUNT 0x20
#define CTRL_REG1 0x2A
#define CTRL_REG2 0x2B
#define CTRL_REG3 0x2C
#define CTRL_REG4 0x2D
#define CTRL_REG5 0x2E

/*
 * Hardware Config
 */

// NRF24L01+ Setup
RF24 radio(GPIO_RF24_CE, GPIO_RF24_CSN);
uint8_t sensorId = 0;

/*
 * Interrupt Registers
 */
volatile uint8_t sensorInterrupt = 0;
volatile uint8_t watchdogCount = 0;
volatile bool statusLedDisable = false;
bool statusLedActive = false;

/*
 * ID Storage (EEPROM)
 */
SensorUid myUid;

/*
 * Data Packets
 */
DataPacket sendPacket, recPacket;

/*
 * Setup / Initialize
 */
void setup(void) {
#if DEBUG
  Serial.begin(115200);
  printf_begin();
  Serial.println(F(""));
  delay(3000);
#endif

  setupUid();
  setupRadio();
  setupSensor();

  // Setup LED Pins
  pinMode(GPIO_LED_R, OUTPUT);
  pinMode(GPIO_LED_G, OUTPUT);
  pinMode(GPIO_LED_B, OUTPUT);

  setLedColor(0,0,0);

  delay(250);

  // Disable Interrupts.
  cli();

  // Setup Watchdog to fire interrupt at 8 second intervals.
  WDTCSR |= (1<<WDCE) | (1<<WDE);
  WDTCSR = (1<<WDIE) | (0<<WDE) | (1<<WDP3) | (0<<WDP2) | (0<<WDP1) | (1<<WDP0);

  // Setup Timer1 to turn off status LED via interrupt.
  TCCR1A = 0;
  TCCR1B = 0;

  // 8 prescaler
  TCCR1B |= (1 << CS11);

  // enable timer overflow interrupt
  TIMSK1 |= (1 << TOIE1);

  // Enable Interrupts.
  sei();

#if DEBUG
  Serial.println(F("Sensor Ready."));
  delay(250);
#endif
}

/*
 * Main Loop
 */
void loop(void) {
  // Turn off status LED after Timer interrupt.
  if (statusLedActive && statusLedDisable) {
    setLedColor(0,0,0);
    statusLedActive = false;
    statusLedDisable = false;
  }

  // Sync to base host and get a sensor id.
  if (sensorId == 0) {
    syncSensor();

    // Ignore any sensor events while we're syncing
    sensorInterrupt = 0;
  }

  if (sensorId != 0) {

    if (sensorInterrupt > 0) {
      // Send sensor trigger packet
      sendSensorTrigger();
      sensorInterrupt = 0;
    }

    // Flash the status LED after a certain number of watchdog cycles.
    if (watchdogCount >= STATUS_FLASH_DELAY) {
      sendSensorStatus();
      enableStatusLed();
      watchdogCount = 0;
    }
  } else {
    // Delay for a while before attempting another sync, this is fine
    // to be blocking (events won't be handled until synced).
    delay(3000);
  }

#if DEBUG
  // Time for serial debug send.
  delay(50);
#endif

  // Enter Sleep.
  enterSleep();
}

/*
 * Turn on the status LED with a color based on the battery status
 */
void enableStatusLed(void) {
#if DEBUG
  Serial.println(F("enableStatusLed: Enabling."));
#endif

#ifdef FEATHER32U4
  uint8_t measuredvbat = getBatteryVoltage();

  if (measuredvbat > BAT_VCC_HIGH) {
    setLedColor(0, 255, 0);
  } else if (measuredvbat > BAT_VCC_MED) {
    setLedColor(255, 255, 66);
  } else {
    setLedColor(255, 0, 0);
  }

#else
  setLedColor(255, 255, 255);
#endif

  statusLedActive = true;
}

/*
 * Enter sleep mode and wait for the next interrupt.
 */
void enterSleep(void) {
  // We need Timer1 active to turn off the LED.
  if (statusLedActive) {
    // set_sleep_mode(SLEEP_MODE_PWR_SAVE);
    return;
  } else {
    set_sleep_mode(SLEEP_MODE_PWR_DOWN);
    power_all_disable();
  }

  sleep_enable();

  // ZZZZZZ...
  sleep_mode();

  // Wake up here.
  sleep_disable();
  power_all_enable();
}

/*
 * Get the current battery voltage (or 3.3 if debug)
 */
uint8_t getBatteryVoltage(void) {

#ifdef FEATHER32U4
  float measuredvbat = analogRead(FEATHER32U4_BATTERY_PIN);
  measuredvbat *= 2;    // we divided by 2, so multiply back
  measuredvbat *= 3.3;  // Multiply by 3.3V, our reference voltage
  measuredvbat /= 1024; // convert to voltage
  measuredvbat *= 10; // Convert to int
  uint8_t vbatint = (uint8_t) measuredvbat;

#else
  uint8_t vbatint = 33;
#endif

#if DEBUG
  printf_P(PSTR("getBatteryVoltage: Voltage %d.\r\n"), vbatint);
#endif

  return(vbatint);
}

/*
 * Setup NRF24L01+ chip.
 */
void setupRadio(void) {

#if DEBUG
  Serial.println(F("setupRadio: Initializing NRF24L01+:"));
#endif

  radio.begin();

  radio.setPayloadSize(sizeof(DataPacket));
  // radio.enableDynamicPayloads();
  radio.setAutoAck(1);

  radio.setDataRate(RF24_1MBPS);
  radio.setPALevel(RF24_PA_LOW);
  radio.setChannel(RADIO_CHANNEL);
  radio.setCRCLength(RF24_CRC_16);
  radio.setRetries(15,15);

  radio.openWritingPipe(control_pipes[1]);
  radio.openReadingPipe(1,control_pipes[0]);

#if DEBUG
  radio.printDetails();
  delay(1000);
#endif

  // Power Down until something happens.
  radio.powerDown();
}

/*
 * Setup MMA8452 Sensor (0.5G Z axis transient motion interrupt).
 */
void setupSensor(void) {
#if DEBUG
  Serial.println(F("setupSensor: Initializing MMA8452."));
#endif
  // TODO Multiple sensor setup
  uint8_t address = ADDR;
  uint8_t intPin = GPIO_MMA_IRQ1;

  // Check who am i = 0x2A
  byte who_am_i = readRegister(address, WHO_AM_I);
  if (who_am_i != 0x2A) {
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

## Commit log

2016-02-02 Initial commit / README
    Add base of arduino_mma8452 sensor code
2016-02-03 Add interrupt handling and I2C helper functions to arduino_mma8452.
2016-02-07 MMA8452 Sensor setup / timers setup / interrupts setup / status LED
2016-02-07 Move LED on timer to Timer2 (Timer1 doesn't wake up the chip).
    [arduino_mma8452.ino]
2016-02-07 Add Feather 32u4 Battery voltage monitor code.
    Add LED color convenience method.
2016-02-07 Add radio send packet on sensor activate (incomplete).
    Add radio / printf debugging.
    Turn off LED on start.
    Clean up debug logging.
    Delay status LED flash on sensor LED flash.
2016-02-09 Add sensor radio payload struct / send.
    Flash yellow on failed / timeout send.
    Power down radio after sending.
    [arduino_mma8452.ino]
2016-02-28 Add sensor sync and status packets sending for MMA8452
    Add RPi / python sensor test script
    Add Feather 32u4 gpio pin defines for MMA8452
    Add dynamic writing pipe selection from sync packet for MMA8452
2016-02-28 Add single data packet struct for all packets
    Clean up packet type numbering
    Clean up RPi sensor test script and update for new packet format
    Add length checking to status and trigger packet recv
2016-08-14 Feather 32u4 timer / interrupt changes.
2016-08-31 Sensor EEPROM id write script
2016-09-17 Teensy base station, initial commit.
2016-09-25 Add base servo / spray / radio state handling (incomplete).
2016-09-25 Add handleSyncRequest to syncronize new / existing sensors.
    Add acknowledgeSensor to send OK response to sensor packets.
    Add desyncronizeSensor to remove / reset sensor id and force resync.
    Update handleRadioPacket for new sub methods.
    Add copyFrom convenience method to SensorUid class.
    [teensy_base.ino]
2016-09-25 Clean up base / sensor pipe addresses for send / recv.
    Add handleSensorData and handleSensorStatus methods to base.
    Change float vbat to uint in DataPacket.
    Add common ct_sensor include to arduino_mma8452 sensor.
2016-09-26 Add Active / Label callback closures to MenuItem class.
    Add active and label callbacks for sensor menu items.
    Clean up extra debug messages.
    Clean up returns on MenuItem fluent interface.
2016-09-26 Add sensor status display menu items.
    Add child and value callbacks to menu items.
2016-09-26 Add editing / editable state to MenuDisplay and MenuItem.
    Add edit callbacks for sensor dir / active and master active.
2016-09-28 Add status display screen w/ sensors, master active and WL.
    Clean up menu interactions and bugs.
    Add activated count to sensor storage.
    Clean up / align power on splash screen.
    [teensy_base.ino]
2016-10-01 Update debug logging messages to be consistent.
    Update pinout defines for updated Feather32u4 hardware.
    Add desync packet support to MMA8452 sensor.
2016-10-02 Draw battery voltage level on sensor icon.
    Add display dim timeout.
    Set sensor edit menu item parent items on sensor child cb.
    Only increment sensor activated count if sensor is active.
2016-10-18 Add Base PCB design files.
    [teensy_base_pcb.kicad_pcb, teensy_base_pcb.sch]
2016-10-19 PCB updates / clean up.
    [teensy_base_pcb.kicad_pcb, teensy_base_pcb.sch]
2016-10-22 More PCB clean up / labels.
    [teensy_base_pcb.kicad_pcb]
2016-10-22 Add accessory / future expansion ports to PCB.
    [teensy_base_pcb.kicad_pcb, teensy_base_pcb.sch]
2016-10-22 Reverse PCB Acc 3.3 / 5V pins and clean up traces.
    [teensy_base_pcb.kicad_pcb, teensy_base_pcb.sch]
2016-10-28 Update schematic for motor driver / component.
    Update capacitor footprints.
    [teensy_base_pcb.sch]
2016-10-29 Update PCB layout for TA8428K motor driver.
    [teensy_base_pcb.kicad_pcb, teensy_base_pcb.sch]
2016-10-29 Clean up traces and fill areas.
    [teensy_base_pcb.kicad_pcb]
2016-10-29 Add resettable fuse / clean up traces / widths.
    [teensy_base_pcb.kicad_pcb, teensy_base_pcb.sch]
2016-10-29 Swap servo output pins and clean up traces.
    [teensy_base_pcb.kicad_pcb, teensy_base_pcb.sch]
2016-10-30 Increase current trace size and clean up labels.
    [teensy_base_pcb.kicad_pcb]
2016-10-30 Move button resistor and more track clean up.
    [teensy_base_pcb.kicad_pcb, teensy_base_pcb.sch]
2016-10-30 More trace cleanup.
    [teensy_base_pcb.kicad_pcb]
2016-10-31 Add document title / rev and set button R value.
    [teensy_base_pcb.kicad_pcb, teensy_base_pcb.sch]
2016-10-31 Rebuild plane fill / final DRC check.
    [teensy_base_pcb.kicad_pcb]
2016-10-31 Update barrel jack for round drill restriction at OSHPark.
    [teensy_base_pcb.kicad_pcb]
2016-11-04 Update base code for PCB pin updates / TA8428 driver / internal pullup.
2016-11-06 Adding initial FreeCAD base model.
    [teensy_base.FCStd]
2016-11-06 More CAD modeling of base.
    [teensy_base.FCStd]
2016-11-07 Add servo / spray nozzle parts to base CAD.
    Add FreeCAD backup files to gitignore.
    [teensy_base.FCStd]
2016-11-08 Add tripod to base CAD.
    [teensy_base.FCStd]
2016-11-16 Add hoses and wires.
    [teensy_base.FCStd]
2016-11-27 Add arduino_mma8452 sensor CAD (incomplete).
    Clean up sketch / layer visibility on base CAD.
    [arduino_mma8452.FCStd, teensy_base.FCStd]
2016-11-27 More updates on arduino_mma8452 CAD.
    [arduino_mma8452.FCStd]
2016-11-27 Complete MMA8452 sensor CAD.
    [arduino_mma8452.FCStd]
2016-11-27 Cut hole for LED in arduino_mma8452 CAD.
    Clean up material rendering / set transparencies on CAD models.
    [arduino_mma8452.FCStd, teensy_base.FCStd]
2016-11-27 Improve MMA8452 CAD USB connector.
    [arduino_mma8452.FCStd]
2016-11-27 Remove unneeded geometry from MMA8452 CAD.
    [arduino_mma8452.FCStd]
2016-12-04 Feather 32u4 / MMA8452 sensor PCB
    [feather32u4_mma8452_pcb.kicad_pcb, feather32u4_mma8452_pcb.sch]
2016-12-06 Clean up wires on arduino_mma8452 CAD.
    [arduino_mma8452.FCStd]
2017-01-16 Clean up export visibility on base FreeCAD model.
    [teensy_base.FCStd]
